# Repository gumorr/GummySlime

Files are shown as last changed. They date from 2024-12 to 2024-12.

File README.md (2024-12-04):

2024-12-03-094416_489x569_scrot

# GummySlime
A Cheesecake compatible SlimeVR tracker PCB.

# Overview
GummySlime is my own take on a Cheesecake PCB. The main features this has over regular Cheesecake PCBs are as follows:
- Designed to be (slightly) possible to solder by hand; this uses 0603 sized SMD components instead of 0402 equivalents. (Emphasis on **slightly**. You MUST be comfortable with SMD soldering.)
- Use of BMI compatible module PCBs instead of soldering the IMU directly on the board itself.
- Use of the ESP32 MCU instead of now outdated ESP12F modules.
- Exposed pads for adding auxilary modules.

# Building
**When you order PCBs, remember to change the PCB thickness to 1mm!**  
Most basic guidelines when building Cheesecake PCBs apply here; the general process is mostly the same. The one "gotcha" you should keep note of while
building is the USB-C connector: you should solder it on **BEFORE** soldering the ESP32 module. It is by far the most difficult component to solder on
to the PCB.

# BOM
| Component | Value  | Quantity |
| --- | --- | --- |
| C1 | [10uF](https://www.digikey.com/en/products/detail/samsung-electro-mechanics/CL10B106MQ8NRNC/3887606) | 1 |
| C2,C3 | [1uF](https://www.digikey.com/en/products/detail/samsung-electro-mechanics/CL10B105KP8NNNC/3887604) | 2 |
| C4 | [0.1uF](https://www.digikey.com/en/products/detail/yageo/CC0603KRX7R7BB104/302822) | 1 |
| CN1 | [USB-C Connector](https://www.digikey.com/en/products/detail/gct/USB4105-GF-A/11198441) | 1 |
| D1 | [Red LED](https://www.digikey.com/en/products/detail/dialight/5973005507F/9385429) | 1 |
| D2 | [Green LED](https://www.digikey.com/en/products/detail/dialight/5973324507F/9385437) | 1 |
| D3 | [1N5819W](https://www.digikey.com/en/products/detail/smc-diode-solutions/1N5819W/15964237) | 1 |
| Q1 | [IRLML6401](https://www.digikey.com/en/products/detail/infineon-technologies/IRLML6401TRPBF/811442) | 1 |
| R1,R2 | [5.1K](https://www.digikey.com/en/products/detail/vishay-dale/RCS06035K10FKEA/5868559) | 2 |
| R3 | [3K](https://www.digikey.com/en/products/detail/vishay-dale/RCS06033K00FKEA/5868535) | 1 |
| R4,R5 | [1K](https://www.digikey.com/en/products/detail/vishay-dale/RCS06031K00FKEA/5866934) | 2 |
| R6,R7 | [100K](https://www.digikey.com/en/products/detail/vishay-dale/RCS0603100KFKEA/5866946) | 2 |
| R8,R9 | [4.7K](https://www.digikey.com/en/products/detail/vishay-dale/RCS06034K70FKEA/5866938) | 2 |
| SW1 | [SSSS811101](https://www.digikey.com/en/products/detail/alps-alpine/SSSS811101/19529062) | 1 |
| U1 | [ESP32-C3-WROOM-02](https://www.digikey.com/en/products/detail/espressif-systems/ESP32-C3-WROOM-02-H4/14553033) | 1 |
| U2 | [IMU Module](https://store.kouno.xyz/products/lsm6dso-module) | 1 |
| U3 | [MIC5504-3.3Y](https://www.digikey.com/en/products/detail/microchip-technology/MIC5504-3-3YM5-TR/4864018) | 1 |
| U4 | [TP4057](https://www.digikey.com/en/products/detail/evvo/TP4057/22482076) | 1 |

# Flashing
You will most likely have to flash using VS Code. Here are all of the relevant settings I personally use for flashing these boards:

### platformio.ini
```
[env:esp32c3]
platform = espressif32 @ 6.7.0
platform_packages =
  framework-arduinoespressif32 @ https://github.com/espressif/arduino-esp32.git#3.0.1
  framework-arduinoespressif32-libs @ https://github.com/espressif/arduino-esp32/releases/download/3.0.1/esp32-arduino-libs-3.0.1.zip
build_flags =
  ${env.build_flags}
  -DESP32C3
  -DARDUINO_USB_MODE=1
  -DARDUINO_USB_CDC_ON_BOOT=1
board = lolin_c3_mini
upload_speed = 921600
```

### defines.h
```
#define IMU IMU_LSM6DSO
#define SECOND_IMU IMU
#define IMU_ROTATION DEG_270
#define SECOND_IMU_ROTATION DEG_270

#define PRIMARY_IMU_OPTIONAL false
#define SECONDARY_IMU_OPTIONAL true

#define BATTERY_MONITOR BAT_EXTERNAL

#define PIN_IMU_SDA 5
#define PIN_IMU_SCL 4
#define PIN_IMU_INT 6
#define PIN_IMU_INT_2 8
#define LED_PIN LED_OFF
//  #define LED_INVERTED false
#define PIN_BATTERY_LEVEL 3

#define BATTERY_SHIELD_RESISTANCE 0
#define BATTERY_SHIELD_R1 100
#define BATTERY_SHIELD_R2 100
```

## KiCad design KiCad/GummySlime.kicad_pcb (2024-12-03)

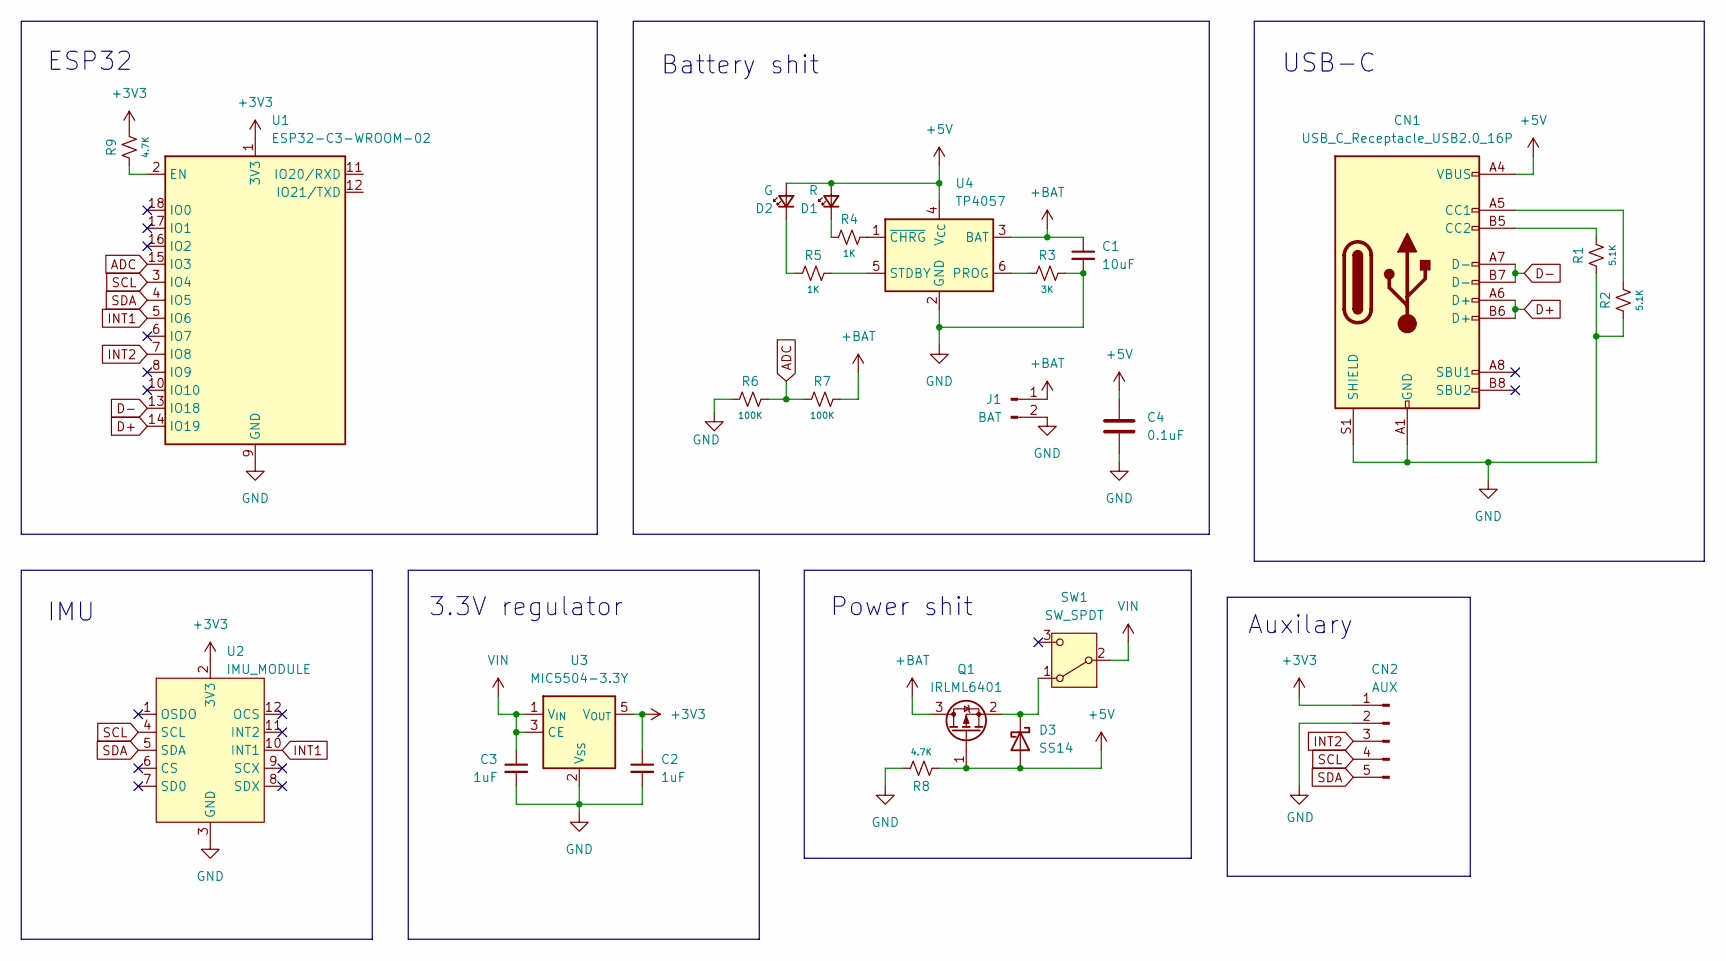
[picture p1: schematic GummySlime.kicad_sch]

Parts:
C1: 10uF; C_0603_1608Metric_Pad1.08x0.95mm_HandSolder
C2, C3: 1uF; C_0603_1608Metric_Pad1.08x0.95mm_HandSolder
C4: 0.1uF; C_0603_1608Metric_Pad1.08x0.95mm_HandSolder
CN1: USB_C_Receptacle_USB2.0_16P; USB_C_Receptacle_GCT_USB4105-xx-A_16P_TopMnt_Horizontal
CN2: AUX; AUX CONNECTOR
D1: R; LED_0603_1608Metric_Pad1.05x0.95mm_HandSolder
D2: G; LED_0603_1608Metric_Pad1.05x0.95mm_HandSolder
D3: SS14; D_SOD-123
J1: BAT; PinHeader_1x02_P2.54mm_Vertical
Q1: IRLML6401; SOT-23
R1, R2: 5.1K; R_0603_1608Metric_Pad0.98x0.95mm_HandSolder
R3: 3K; R_0603_1608Metric_Pad0.98x0.95mm_HandSolder
R4, R5: 1K; R_0603_1608Metric_Pad0.98x0.95mm_HandSolder
R6, R7: 100K; R_0603_1608Metric_Pad0.98x0.95mm_HandSolder
R8, R9: 4.7K; R_0603_1608Metric_Pad0.98x0.95mm_HandSolder
SW1: SW_SPDT; SW_SPDT_PCM12
U1: ESP32-C3-WROOM-02
U2: IMU_MODULE; BMI_LSM
U3: MIC5504-3.3Y; SOT-23-5_HandSoldering
U4: TP4057; TSOT-23-6

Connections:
+3V3: C2.1, CN2.1, R9.2, U1.1 (3V3), U2.2 (3V3), U3.5 (V_{OUT})
+5V: C4.1, CN1.A4 (VBUS), CN1.A9 (VBUS), CN1.B4 (VBUS), CN1.B9 (VBUS), D1.2 (A), D2.2 (A), D3.2 (A), Q1.1 (G), R8.1, U4.4 (V_{CC})
+BAT: C1.1, J1.1, Q1.3 (D), R7.2, U4.3 (BAT)
ADC: R6.2, R7.1, U1.15 (IO3)
D+: CN1.A6 (D+), CN1.B6 (D+), U1.14 (IO19)
D-: CN1.A7 (D-), CN1.B7 (D-), U1.13 (IO18)
GND: C1.2, C2.2, C3.2, C4.2, CN1.A1 (GND), CN1.A12 (GND), CN1.B1 (GND), CN1.B12 (GND), CN1.S1 (SHIELD), CN2.2, J1.2, R1.1, R2.1, R3.2, R6.1, R8.2, U1.9 (GND), U1.19 (GND), U2.3 (GND), U3.2 (V_{SS}), U4.2 (GND)
INT1: U1.5 (IO6), U2.10 (INT1)
INT2: CN2.3, U1.7 (IO8)
unnamed: CN1.A5 (CC1), R2.2
unnamed: CN1.B5 (CC2), R1.2
unnamed: D1.1 (K), R4.1
unnamed: D2.1 (K), R5.1
unnamed: D3.1 (K), Q1.2 (S), SW1.1 (A)
unnamed: R9.1, U1.2 (EN)
unnamed: R3.1, U4.6 (PROG)
unnamed: R5.2, U4.5 (STDBY)
unnamed: R4.2, U4.1 (~CHRG)
SCL: CN2.4, U1.3 (IO4), U2.4 (SCL)
SDA: CN2.5, U1.4 (IO5), U2.5 (SDA)
VIN: C3.1, SW1.2 (B), U3.1 (V_{IN}), U3.3 (CE)

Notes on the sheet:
Power shit
USB-C
3.3V regulator
Auxilary
ESP32
Battery shit
IMU

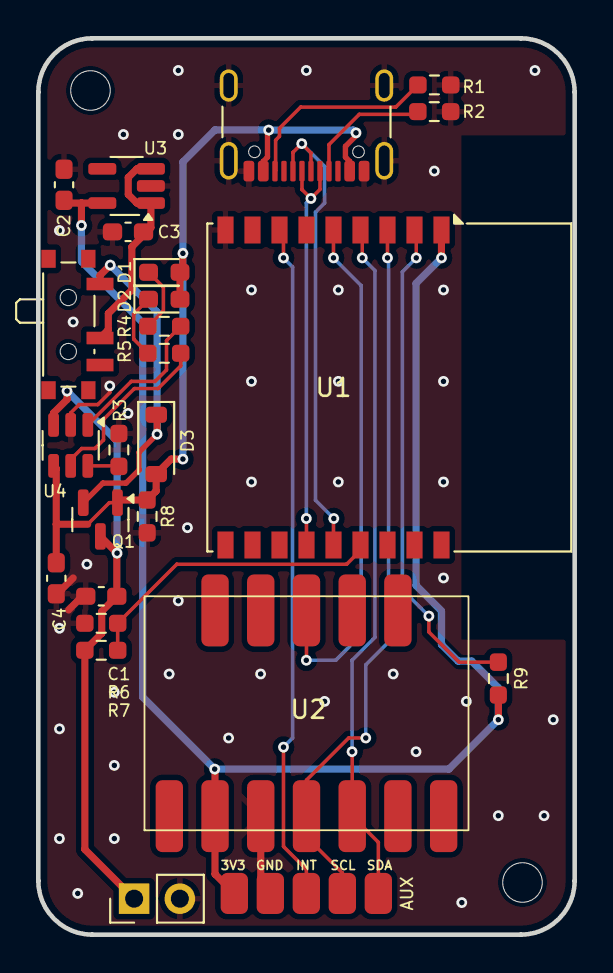
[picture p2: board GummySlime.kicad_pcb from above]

Board: 2 copper layers, 29.8 x 49.8 mm, 25 parts (0 on the bottom side), 21 nets.
